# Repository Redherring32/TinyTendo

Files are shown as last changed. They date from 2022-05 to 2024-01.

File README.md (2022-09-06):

# Tiny 'Tendo
An open-source Gameboy sized handheld NES using real hardware

## DISCLAIMER:

TinyTendo is a complex project that has taken a ton of effort, and despite now being open source should still be considered somewhat experimental, should you find anything that isn't quite right, please file an issue.

Additionally, TinyTendo requires physically cutting and grinding ORIGINAL NES chips down smaller, this is a difficult, tedious, and risky process. 

You could KILL the chips if this is not done correctly, do this at your own risk, I am not responsible for damage to any hardware resulting from attempting to build this project.

## Repository Structure:

* Hardware: Contains all files relating to the hardware design for the various PCBs used for this project

* Software: Contains the software required for the brightness mod PCB

* 3D-CAD: Contains design files for the housing design

The files required to order PCBs can be found under releases.

TinyTendo Internals
	
This project is a derivitive of OpenTendo, and OpenTendo-Toploader, and is licensed accordingly. Please read the LICENSE in the repository for more info.

Since this project is open-source you may do as you like with it, whether that is to make TinyTendo for personal use, sell PCBs or assembled handhelds, or to use the provided info for further custom PCB work/designs.

*Note:* 
REAL NES chips from a real NES are required, clone chips cannot be used without some redesign of the motherboard, as they cannot be trimmed down as small.
A version of the PCB that supports them would be relatively easy to make, but I myself have no interest in doing so. (PRs to add a "clone" branch are welcome!)

And finally, I am NOT an EE, if you are at all disgusted by any aspect of the PCB designs, I am sorry. (PRs for this are also welcome :P)

## TO-DO:

* Write chip trimming guide to go over workflow and best practices

* Update readme image to reflect current hardware revision

* Figure out what I am forgetting to add to TO-DO

## License:

Licensed under
the TAPR Open Hardware License (www.tapr.org/OHL)

©Redherring32 2019-2022

All hardware contained within this repository was designed by me except the Brightness mod PCB.
The brightness mod PCB was designed by YveltalGriffin, and has been licensed under TAPR OHL with permission from the author.
The brightness PCB was designed using Eagle, all other hardware was designed using KiCAD.
The Brightness software was written by YveltalGriffin, and has been licensed under MIT with permission from the author, see LICENSE in software folder for details.
## Credits

In no particular order:

*FenrisWolfRetro* -Creating the wiring diagram in the Hardware folder.

*YveltalGriffin* -Designed the brightness mod PCB, and wrote the code for it, and was just a tremendous help.

*DiscoStarslayer* -Helping to inspire me to trim the chipset, without his joking suggestion to dremel the package and solder to the leads, I would not have started researching chip trimming.

*lidnariq* -Helping me diagnose my idiotic design blunders, might not have had the motivation to keep going on the project without their help.

*BucketMouse* -Designing cartridge PCBs for TinyTendo, and help with diagnosis work.

*MuraMasa* -Help with diagnosis work, sharing KiCAD footprints for early protos cause I kept messing mine up. :)

And to all of the awesome people in NESDev, you guys rock.

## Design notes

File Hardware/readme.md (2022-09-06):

Wiring Diagram made by FenrisWolfRetro

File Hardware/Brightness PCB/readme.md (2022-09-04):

Brightness PCB

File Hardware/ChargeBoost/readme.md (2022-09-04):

ChargeBoost

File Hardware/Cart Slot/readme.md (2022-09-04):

Cart Slot

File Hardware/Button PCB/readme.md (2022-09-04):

Button PCB

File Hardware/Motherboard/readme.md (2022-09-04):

PCB Photo

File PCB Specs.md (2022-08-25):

##PCB SPECS:

##Motherboard:
*4-Layers
*1.6mm thickness
*HASL finish

##ChargeBoost:
*2-Layers
*1.6mm thickness
*HASL finish

##AudioAmp
*2-Layers
*1.6mm thickness
*ENiG finish

##Button PCB:
*2-Layers
*1.6mm thickness
*ENiG finish

##Composite Amp:
*2-layers 
*0.6mm thickness
*HASL finish

##Brightness PCB:
*2-Layers
*1.6mm thickness
*HASL finish

##Cart SLot:
*2-Layers
*1.6mm thickness
*HASL finish

##Cart-Test:
*2-Layers
*1.6mm thickness
*ENiG finish

##TNY-NES-Adapter:
*2-Layers 
*1.2mm thickness
*ENiG finish

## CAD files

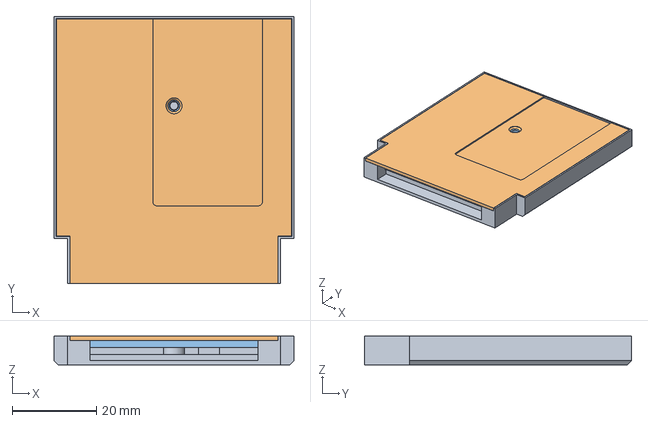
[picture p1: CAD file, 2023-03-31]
3D-CAD/TinyTendo Cartridge-Shell.step
57.0 x 63.5 x 6.80 mm

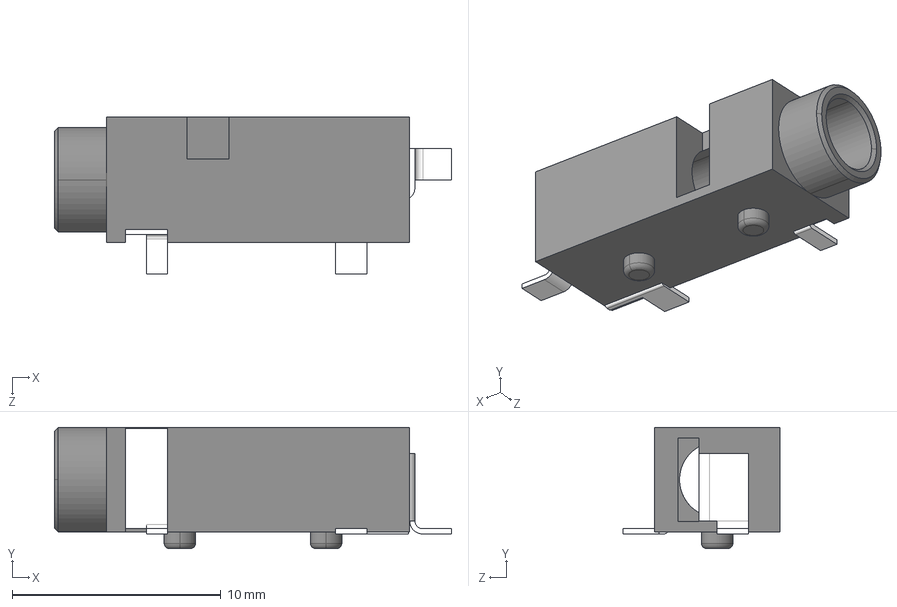
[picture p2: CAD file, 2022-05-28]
Hardware/Audio Amp/CUI_DEVICES_MJ-3523-SMT-TR.step
19.0 x 5.80 x 7.50 mm

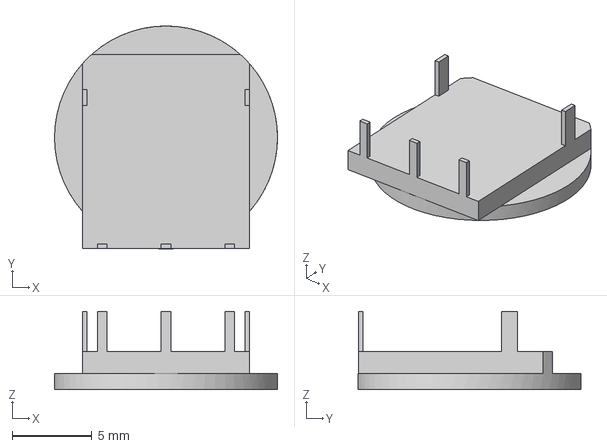
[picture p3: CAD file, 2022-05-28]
Hardware/Composite amp/Thumbwheel Pot v1.step
14.0 x 14.0 x 4.90 mm

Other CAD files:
3D-CAD/TinyTendo Cartridge-Shell.f3d

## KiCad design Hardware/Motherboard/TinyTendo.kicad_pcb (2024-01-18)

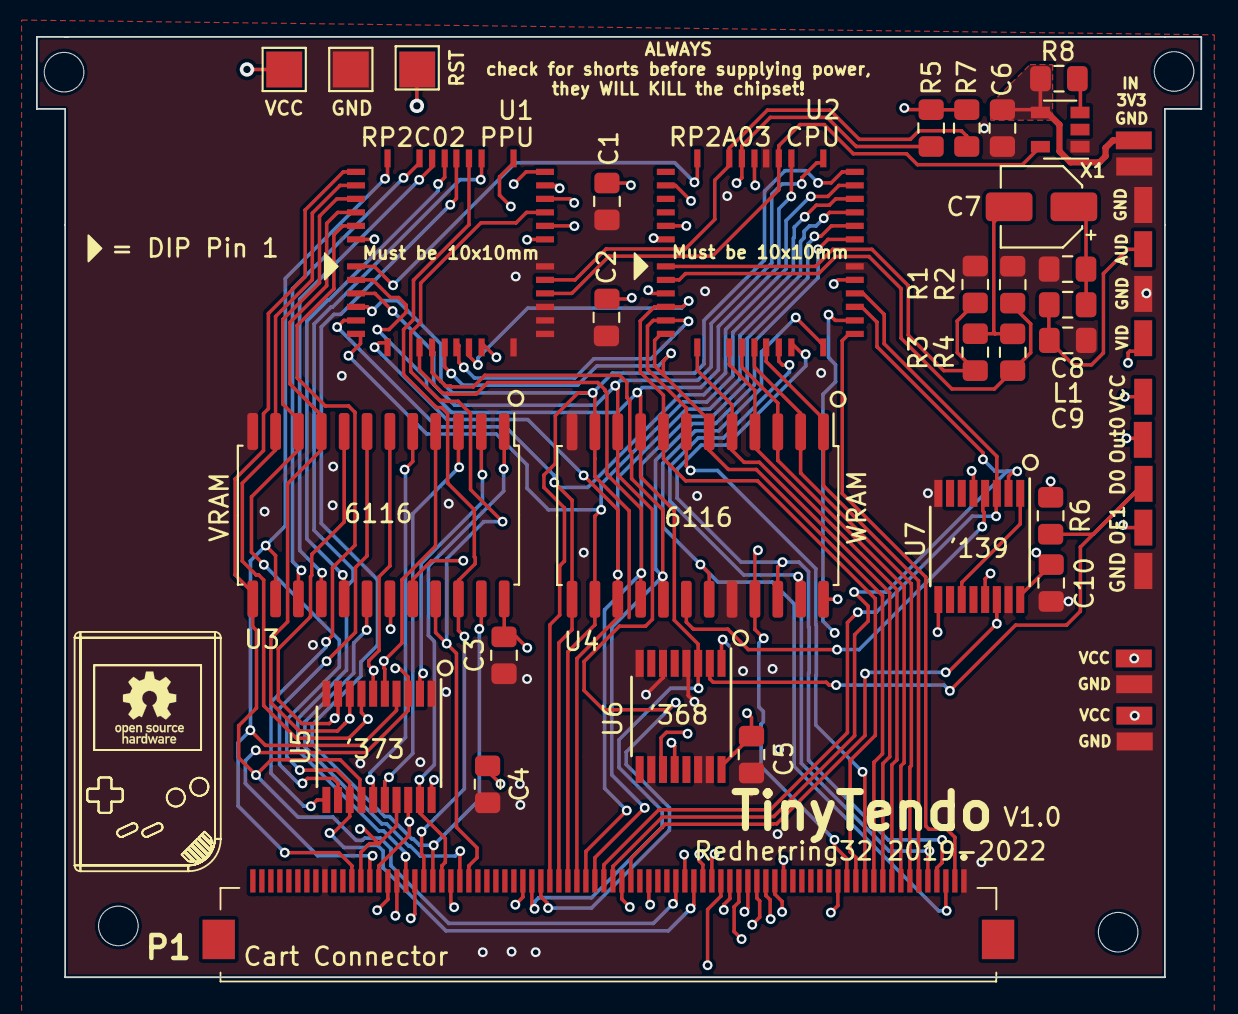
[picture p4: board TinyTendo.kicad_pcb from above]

Board: 4 copper layers, 64.7 x 52.2 mm, 50 parts (0 on the bottom side), 75 nets.

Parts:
C1, C2, C4, C5, C10: 10nF; C_0805_2012Metric_Pad1.15x1.40mm_HandSolder
C3, C6, C9: 0.1uF; C_0805_2012Metric_Pad1.15x1.40mm_HandSolder
C7: 1uF; CP_Elec_4x5.3
C8: 220pF; C_0805_2012Metric_Pad1.15x1.40mm_HandSolder
H1, H2, H3, H4: MountingHole_2.2mm_M2
J1, J2, J2#2, J2#3, J4#2, J5#2, J6, J6#2, J6#3, J6#4, J6#5, J7, J7#2, J8, J9: Conn_01x01_Male; SolderPad
J3, J4, J5: Conn_01x01_Male; TestPoint_Pad_2.0x2.0mm
L1: 39uH; L_0805_2012Metric_Pad1.15x1.40mm_HandSolder
P1: 72-Pin Connector; XF3M80151BE
R1, R2: 160; R_0805_2012Metric_Pad1.15x1.40mm_HandSolder
R3: 200; R_0805_2012Metric_Pad1.15x1.40mm_HandSolder
R4: 100; R_0805_2012Metric_Pad1.15x1.40mm_HandSolder
R5, R6, R7: 10K; R_0805_2012Metric_Pad1.15x1.40mm_HandSolder
R8: 1K; R_0805_2012Metric_Pad1.15x1.40mm_HandSolder
U1: RP2C02 PPU; Cut chip
U2: RP2A03 CPU; Cut chip
U3: 6116 (VRAM); SOIC-24W_7.5x15.4mm_P1.27mm
U4: 6116 (WRAM); SOIC-24W_7.5x15.4mm_P1.27mm
U5: 74HC373; TSSOP-20_4.4x6.5mm_P0.65mm
U6: 40H368 (CI); TSSOP-16_4.4x5mm_P0.65mm
U7: 74HC139; TSSOP-16_4.4x5mm_P0.65mm
X1: SiT2001B; SOT-23-5

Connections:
/3V3: C6.2, J1.1, R8.2, X1.4
/4016-D0: J4#2.1, R6.2, U6.2
/ALE: U1.39, U5.11
/AUDIO: C9.1, J8.1, L1.2
/CPU-A0: P1.13, U1.12, U2.4, U4.8
/CPU-A1: P1.12, U1.11, U2.5, U4.7
/CPU-A2: P1.11, U1.10, U2.6, U4.6
/CPU-A3: P1.10, U2.7, U4.5
/CPU-A4: P1.9, U2.8, U4.4
/CPU-A5: P1.8, U2.9, U4.3
/CPU-A6: P1.7, U2.10, U4.2
/CPU-A7: P1.6, U2.11, U4.1
/CPU-A8: P1.5, U2.12, U4.23
/CPU-A9: P1.4, U2.13, U4.22
/CPU-A10: P1.3, U2.14, U4.19
/CPU-A11: P1.2, U2.15
/CPU-A12: P1.39, U2.16
/CPU-A13: P1.40, U2.17, U7.2
/CPU-A14: P1.41, U2.18, U7.3
/CPU-A15: U2.19, U7.13
/CPU-D0: P1.49, U1.2, U2.28, U4.9, U6.3
/CPU-D1: P1.48, U1.3, U2.27, U4.10
/CPU-D2: P1.47, U1.4, U2.26, U4.11
/CPU-D3: P1.46, U1.5, U2.25, U4.13
/CPU-D4: P1.45, U1.6, U2.24, U4.14
/CPU-D5: P1.44, U1.7, U2.23, U4.15
/CPU-D6: P1.43, U1.8, U2.22, U4.16
/CPU-D7: P1.42, U1.9, U2.21, U4.17
/CPU-R~W: P1.14, U1.1, U2.34, U4.21
/GND: C1.1, C2.1, C3.1, C4.1, C5.1, C6.1, C8.1, C9.2, C10.1, J2.1, J2#2.1, J2#3.1, J3.1, J6#4.1, J7.1, J7#2.1, P1.1, P1.72, R1.1, R2.1, U1.14, U1.15, U1.16, U1.17, U1.20, U2.20, U2.30, U3.12, U4.12, U4.20, U5.1, U5.10, U6.4, U6.6, U6.8, U6.10, U6.14, U6.15, U7.8, U7.15, X1.1
/M2: P1.38, U2.31, U7.14
/OUT-0: J5#2.1, U2.39
/PPU-A0: P1.29, U3.8, U5.9
/PPU-A1: P1.28, U3.7, U5.12
/PPU-A2: P1.27, U3.6, U5.6
/PPU-A3: P1.26, U3.5, U5.15
/PPU-A4: P1.25, U3.4, U5.5
/PPU-A5: P1.24, U3.3, U5.16
/PPU-A6: P1.23, U3.2, U5.2
/PPU-A7: P1.59, U3.1, U5.19
/PPU-A8: P1.60, U1.30, U3.23
/PPU-A9: P1.61, U1.29, U3.22
/PPU-A10: P1.63, U1.28
/PPU-A11: P1.62, U1.27
/PPU-A12: P1.64, U1.26
/PPU-A13: P1.65, U1.25, U6.12
/PPU-D0: P1.30, U1.38, U3.9, U5.8
/PPU-D1: P1.31, U1.37, U3.10, U5.13
/PPU-D2: P1.32, U1.36, U3.11, U5.7
/PPU-D3: P1.33, U1.35, U3.13, U5.14
/PPU-D4: P1.69, U1.34, U3.14, U5.4
/PPU-D5: P1.68, U1.33, U3.15, U5.17
/PPU-D6: P1.67, U1.32, U3.16, U5.3
/PPU-D7: P1.66, U1.31, U3.17, U5.18
/PPU-~A13: P1.58, U6.11
/PPU-~CE: U1.13, U7.5
/PPU-~RD: P1.21, U1.24, U3.20
/PPU-~WE: P1.56, U1.23, U3.21
/SOUND-1: R1.2, R3.2, U2.1
/SOUND-2: R2.2, R4.2, U2.2
/SYS-CLK: U1.18, U2.29, X1.5
/VCC: C1.2, C2.2, C3.2, C4.2, C5.2, C10.2, J4.1, J6.1, J6#2.1, J6#3.1, P1.36, R5.1, R6.1, R7.1, U1.22, U1.40, U2.40, U3.24, U4.24, U5.20, U6.16, U7.16
/VIDEO: J9.1, U1.21
/VRAM-A10: P1.22, U3.19
/VRAM-~CE: P1.57, U3.18
/WRAM-~CE: U4.18, U7.4
/~IRQ: P1.15, R5.2, U2.32
/~NMI: R7.2, U1.19, U2.33
/~OE1: J6#5.1, U2.36, U6.1
/~ROMSEL: P1.50, U7.9
/~RST: J5.1, U2.3
unnamed: C7.1, C8.2, L1.1
unnamed: C7.2, R3.1, R4.1
unnamed: R8.1, X1.3
unnamed: U7.1, U7.11

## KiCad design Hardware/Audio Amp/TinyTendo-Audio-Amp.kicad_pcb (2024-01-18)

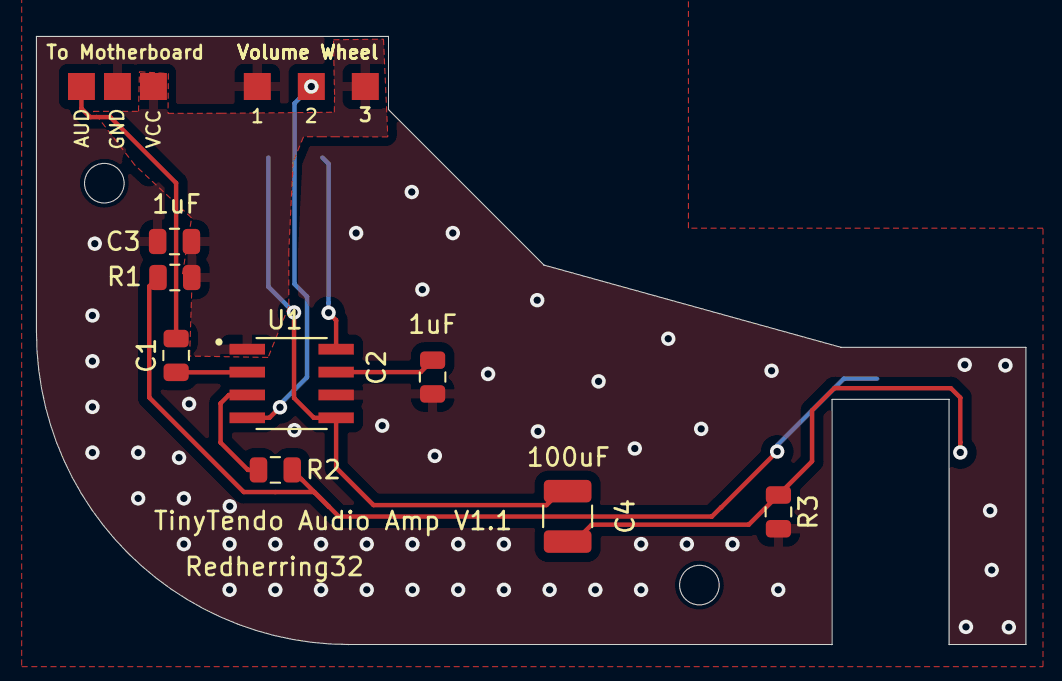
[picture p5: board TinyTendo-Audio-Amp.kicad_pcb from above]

Board: 2 copper layers, 55.0 x 33.8 mm, 14 parts (0 on the bottom side), 11 nets.

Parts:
 : MountingHole_2.2mm_M2
 #2: MountingHole_2.2mm_M2
C1: 0.22uF; C_0805_2012Metric
C2, C3: 1uF; C_0805_2012Metric
C4: 100uF; C_1210_3225Metric
J1: Conn_Coaxial; AUD-IN
J2: MJ-3523-SMT; CUI_MJ-3523-SMT-Inline
LS1: Speaker
R1, R2: 100K; R_0805_2012Metric
R3: 150R; R_0805_2012Metric
U1: LM4865M; SOIC127P599X175-8N
Volume Wheel: 10K; VolPot

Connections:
/GND: C2.2, C3.2, J1.2, J2.1, R3.2, U1.6, Volume Wheel.3
/VDD: C3.1, J1.3, R1.1, U1.1, Volume Wheel.1
unnamed: C1.1, U1.2
unnamed: C1.2, J1.1
unnamed: C2.1, U1.7
unnamed: C4.1, LS1.1, U1.5
unnamed: C4.2, J2.2, R3.1
unnamed: J2.10, R1.2, R2.1
unnamed: LS1.2, U1.8
unnamed: R2.2, U1.3
unnamed: U1.4, Volume Wheel.2

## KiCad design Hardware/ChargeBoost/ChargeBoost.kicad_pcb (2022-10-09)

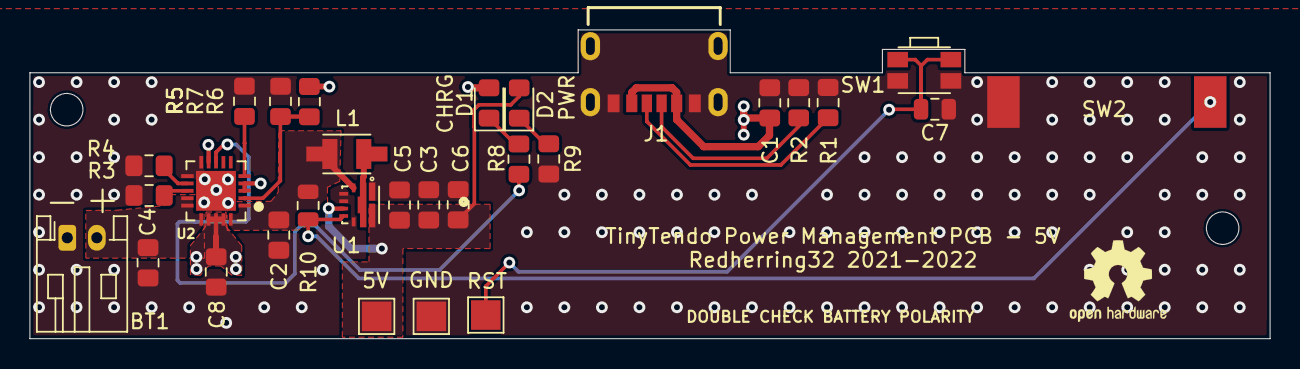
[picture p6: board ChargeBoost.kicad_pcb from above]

Board: 2 copper layers, 84.0 x 20.9 mm, 32 parts (0 on the bottom side), 17 nets.

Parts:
 : MountingHole_2.2mm_M2
 #2: MountingHole_2.2mm_M2
BT1: 2800mAh; JST_PH_S2B-PH-K_1x02_P2.00mm_Horizontal-Mirrored
C1, C2, C4, C8: 10uF; C_0805_2012Metric_Pad1.15x1.40mm_HandSolder
C3, C5, C6: 22uF; C_0805_2012Metric_Pad1.15x1.40mm_HandSolder
C7: 1uF; C_0805_2012Metric
D1: Red; LED_0805_2012Metric_Pad1.15x1.40mm_HandSolder
D2: BLUE; LED_0805_2012Metric_Pad1.15x1.40mm_HandSolder
J1: USB4125-GF-A_REVA2; GCT_USB4125-GF-A_REVA2
J3, J4, J5: Conn_01x01_Male; TestPoint_Pad_2.0x2.0mm
L1: 1uH; IND_LQH32CN1R0M23L
R1, R2: 5K1; R_0805_2012Metric_Pad1.15x1.40mm_HandSolder
R3, R8: 1K; R_0805_2012Metric_Pad1.15x1.40mm_HandSolder
R4, R7: 100K; R_0805_2012Metric_Pad1.15x1.40mm_HandSolder
R5: 15K; R_0805_2012Metric_Pad1.15x1.40mm_HandSolder
R6: 270K; R_0805_2012Metric_Pad1.15x1.40mm_HandSolder
R9: 91R; R_0805_2012Metric_Pad1.15x1.40mm_HandSolder
R10: 200R; R_0805_2012Metric
SW1: SW_Push; SW_SPST_EVQP7A
SW2: PWR
U1: TPS61235PRWLT; CONV_TPS61235PRWLT
U2: MCP73871-2AAI_ML; QFN50P400X400X100-21N

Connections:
/GND: BT1.2, C1.2, C2.2, C3.2, C4.2, C5.2, C6.2, C7.2, C8.2, J1.A12, J1.B12, J1.S1, J3.1, R1.2, R2.2, R3.2, R4.2, R5.2, R7.2, R9.2, SW1.1, SW2.1, U1.1, U1.4, U1.5, U1.8, U2.10, U2.11, U2.21
/RST: C7.1, J5.1, SW1.2
/VBAT: C2.1, L1.1, R10.1, U1.3, U2.1, U2.20
/VBUS: C1.1, C8.1, D1.2, J1.A9, J1.B9, R6.1, U2.3, U2.4, U2.9, U2.17, U2.18, U2.19
/VOUT: C3.1, C5.1, C6.1, D2.2, J4.1, U1.6, U1.9
unnamed: BT1.1, C4.1, U2.14, U2.15, U2.16
unnamed: D1.1, R8.1
unnamed: D2.1, R9.1
unnamed: J1.A5, R2.1
unnamed: J1.B5, R1.1
unnamed: L1.2, U1.2
unnamed: R3.1, U2.13
unnamed: R4.1, U2.12
unnamed: R5.1, U2.5
unnamed: R6.2, R7.1, U2.2
unnamed: R8.2, U2.8
unnamed: R10.2, SW2.2, U1.7

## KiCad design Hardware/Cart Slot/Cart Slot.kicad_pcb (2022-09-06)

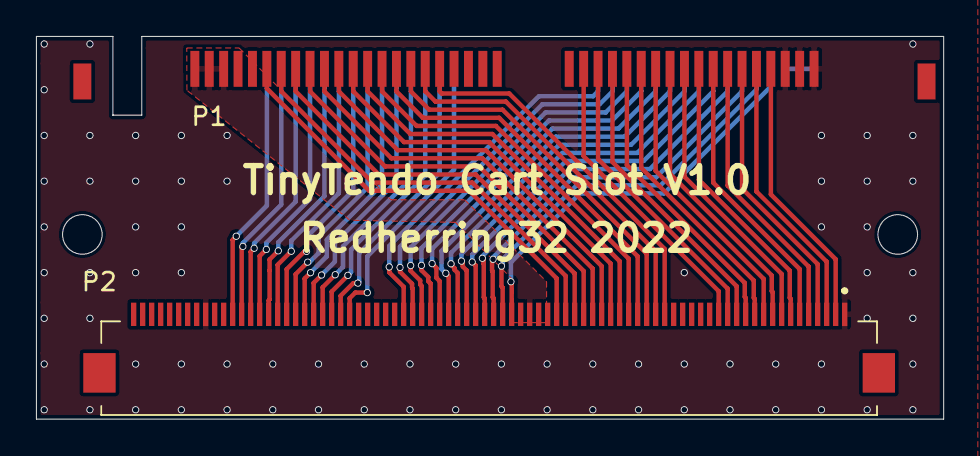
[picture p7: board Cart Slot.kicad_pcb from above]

Board: 2 copper layers, 50.4 x 21.3 mm, 4 parts (0 on the bottom side), 56 nets.

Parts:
 : MountingHole_2.2mm_M2
 #2: MountingHole_2.2mm_M2
P1: 72-Pin Connector; Cart Slot
P2: 72-Pin Connector; XF3M80151BE

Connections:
/CPU-A0: P1.13, P2.13
/CPU-A1: P1.12, P2.12
/CPU-A2: P1.11, P2.11
/CPU-A3: P1.10, P2.10
/CPU-A4: P1.9, P2.9
/CPU-A5: P1.8, P2.8
/CPU-A6: P1.7, P2.7
/CPU-A7: P1.6, P2.6
/CPU-A8: P1.5, P2.5
/CPU-A9: P1.4, P2.4
/CPU-A10: P1.3, P2.3
/CPU-A11: P1.2, P2.2
/CPU-A12: P1.39, P2.39
/CPU-A13: P1.40, P2.40
/CPU-A14: P1.41, P2.41
/CPU-D0: P1.49, P2.49
/CPU-D1: P1.48, P2.48
/CPU-D2: P1.47, P2.47
/CPU-D3: P1.46, P2.46
/CPU-D4: P1.45, P2.45
/CPU-D5: P1.44, P2.44
/CPU-D6: P1.43, P2.43
/CPU-D7: P1.42, P2.42
/CPU-R~W: P1.14, P2.14
/GND: P1.1, P1.72, P2.1, P2.72
/M2: P1.38, P2.38
/PPU-A0: P1.29, P2.29
/PPU-A1: P1.28, P2.28
/PPU-A2: P1.27, P2.27
/PPU-A3: P1.26, P2.26
/PPU-A4: P1.25, P2.25
/PPU-A5: P1.24, P2.24
/PPU-A6: P1.23, P2.23
/PPU-A7: P1.59, P2.59
/PPU-A8: P1.60, P2.60
/PPU-A9: P1.61, P2.61
/PPU-A10: P1.63, P2.63
/PPU-A11: P1.62, P2.62
/PPU-A12: P1.64, P2.64
/PPU-A13: P1.65, P2.65
/PPU-D0: P1.30, P2.30
/PPU-D1: P1.31, P2.31
/PPU-D2: P1.32, P2.32
/PPU-D3: P1.33, P2.33
/PPU-D4: P1.69, P2.69
/PPU-D5: P1.68, P2.68
/PPU-D6: P1.67, P2.67
/PPU-D7: P1.66, P2.66
/PPU-~A13: P1.58, P2.58
/PPU-~RD: P1.21, P2.21
/PPU-~WE: P1.56, P2.56
/VCC: P1.36, P2.36
/VRAM-A10: P1.22, P2.22
/VRAM-~CE: P1.57, P2.57
/~IRQ: P1.15, P2.15
/~ROMSEL: P1.50, P2.50

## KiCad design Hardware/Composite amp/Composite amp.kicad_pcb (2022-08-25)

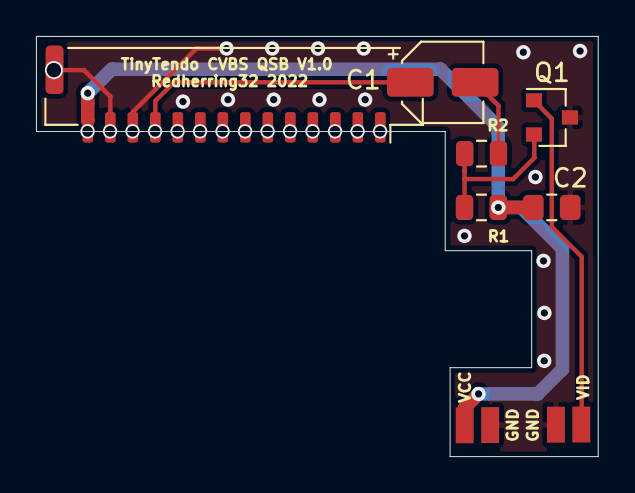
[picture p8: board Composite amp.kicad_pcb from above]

Board: 2 copper layers, 31.2 x 23.3 mm, 10 parts (0 on the bottom side), 6 nets.

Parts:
C1: 100uF; CP_Elec_4x4.5
C2: 22uF; C_0805_2012Metric_Pad1.15x1.40mm_HandSolder
GND1, GND2: TestPoint; SolderPad
J1: Conn_01x14_Female; JST_GH_SM14B-GHS-TB_1x14-1MP_P1.25mm_Horizontal
Q1: MMBT3906; SOT-23
R1: 300R; R_0805_2012Metric
R2: 110R; R_0805_2012Metric
VCC1: TestPoint; SolderPad
VID1: TestPoint; SolderPad

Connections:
/5V: C2.1, J1.14, R1.1, VCC1.1
/GND: C2.2, GND1.1, GND2.1, J1.12, J1.13, Q1.3
/VIDEO-IN: Q1.1, VID1.1
/VIDEO-OUT: C1.1, J1.11
unnamed: C1.2, R2.1
unnamed: Q1.2, R1.2, R2.2

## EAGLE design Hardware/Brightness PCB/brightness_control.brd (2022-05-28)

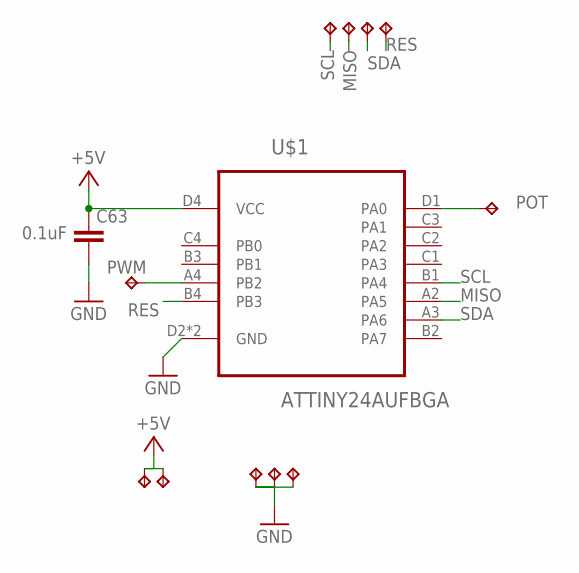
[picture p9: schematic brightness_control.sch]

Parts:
C63: 0.1uF; C0402
TP1, TP3, TP4, TP5, TP6, TP7, TP8, TP10, TP11, TP12, TP13: TPTP12R; TP12R
U$1: ATTINY24AUFBGA; UFBGA-15

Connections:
+5V: C63.1, TP3.TP, TP4.TP, U$1.D4 (VCC)
GND: C63.2, TP1.TP, TP5.TP, TP6.TP, U$1.D2 (GND), U$1.D3 (GND)
MISO: TP11.TP, U$1.A2 (PA5)
POT: TP7.TP, U$1.D1 (PA0)
PWM: TP8.TP, U$1.A4 (PB2)
RES: TP13.TP, U$1.B4 (PB3)
SCL: TP10.TP, U$1.B1 (PA4)
SDA: TP12.TP, U$1.A3 (PA6)

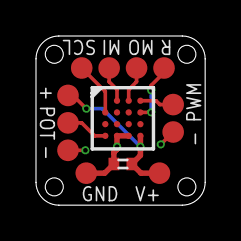
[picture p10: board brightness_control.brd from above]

Board: 2 copper layers, 9.4 x 9.4 mm, 13 parts (0 on the bottom side), 8 nets.

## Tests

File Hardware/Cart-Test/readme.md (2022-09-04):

Cart Test

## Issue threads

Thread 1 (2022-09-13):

EN pull-up resistor missing on ChargeBoost

Redherring32, 2022-09-13:
The pull up resistor for the buck boost enable line is missing on the ChargeBoost PCB (Really not sure what happened), working on a fix currently.

Redherring32, 2022-10-09:
Fixed by Pull Request #2

Closed 2022-10-09.

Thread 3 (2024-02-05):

White screen

GenuineHili, 2024-02-05:
So I assembled the motherboard, charge boost pcb and cart slot pcb and gave it a try but I always get a white screen when I turn it on.
I tested the cartridge with the cart test, so I know the cartridge is working. Is the audio pcb and button pcb mandatory for the NES to boot?

Pearus, 2024-02-05:
> So I assembled the motherboard, charge boost pcb and cart slot pcb and gave it a try but I always get a white screen when I turn it on. I tested the cartridge with the cart test, so I know the cartridge is working. Is the audio pcb and button pcb mandatory for the NES to boot?

Audio and button PCBs are not required for booting. If you're getting a white screen, double check the connections on the CPU. If you have the board to test full sized games, that's another good thing to try to confirm if it's something with the connection to the TinyTendo cartridge slot.

GenuineHili, 2024-03-11:
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
It's working now. I resoldered the 80-pin connector on the cart slot PCB and now it's working. Thank you for your advice.

Pearus, 2024-03-11:
> ![IMG_20240311_132507285](https://private-user-images.githubusercontent.com/147345143/311771046-8b41c50a-c64d-402c-a06b-0a79d4b32b41.jpg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) It's working now. I resoldered the 80-pin connector on the cart slot PCB and now it's working. Thank you for your advice.

Awesome, glad you got it running!

Closed 2024-03-11.

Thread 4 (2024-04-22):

Brightness Mod

GenuineHili, 2024-04-22:
Is it normal that the screen is rather dark compared to when it's not installed, even when the brightness wheel is all the way up?

Pearus, 2024-04-23:
I experienced the same, the brightness was significantly lower.

You can play around with max brightness by adjusting "15" in the Arduino sketch to values between 0 and 255:
`analogWrite(8, map(pot, 0, 1023, 0, 15));`

I would be careful and start with small increments.

GenuineHili, 2024-04-24:
Ok I set the value to 100 and now it's nice and bright. Thank you for your help.

Closed 2024-04-24.

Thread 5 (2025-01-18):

Parasitic Drain with ChargeBoost PCB

Pearus, 2025-01-18:
There's a known issue with the ChargeBoost PCB which causes parasitic drain. Resistor R10 on the EN pin of the TPS61235PRWLT is configured as a pull-up resistor instead of a pull-down resistor.

The workaround to resolve the parasitic drain is to do the following:

1.  Move resistor R10 so that the bottom is aligned with the ground side of capacitor C2 and the top is soldered to the pad connected to the EN pin of the TPS61235PRWLT.
2. Connect the ground side of capacitor C2 to the bottom of resistor R10 using a wire, lead, or solder blob.

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

3. Connect a wire to the original pad the top of resistor R10 was connected to, long enough to reach the left lead of the power switch.

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

4.  De-solder the left leg of the power switch from the ground pad and cover the pad with Kapton tape or another non-conductive material.
5. Connect the soldered wire to the left leg of the power switch.

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

GenuineHili, 2025-01-20:
Yo, thanks for that workaround. I always thought that my battery cells are the problem.
The only downside to this is that the power switch is inverted, which isn't a big deal.

GenuineHili, 2025-01-20:
Ok I will try it with a 10k resistor and measure the voltage over some days.

GenuineHili, 2025-01-30:
Ok so with a 10k resistor the voltage drops about 0,007V per day. I then tried the same with a 200k resistor where the voltage drops about 0,002V per day. So that's basically nothing.

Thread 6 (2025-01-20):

Undersized Capacitor C2 on ChargeBoost PCB

Pearus, 2025-01-20:
Capacitor C2 on the ChargeBoost may be undersized, resulting in voltage drops which prevent the TPS61235PRWLT from boosting to 5V. This is more noticeable when the batteries are not fully charged.

To fix this a second capacitor can be stacked on top of C2, this can be of the same value or higher.

GenuineHili, 2025-01-21:
Does that mean that the recommend value for C2 is around 22µF?

Pearus, 2025-01-21:
> Does that mean that the recommend value for C2 is around 22µF?

Yup, that should work, I just stacked a second 10µF on top because that's what I had.

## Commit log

2022-05-28 + Add Working Files + Initial Readme Draft
    [Button PCB.kicad_pcb, Button PCB.sch, Button PCB.step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]
2022-05-29 + Updated README.md + Fixed schematic/pinout error with Q1, and added decoupling capacitor to Composite Amp
    [Composite amp.kicad_pcb, Composite amp.sch]
2022-06-15 + Motherboard is now V1.0 + Redesigned ScreenReg for improved reliability + Added both versions of ChargeBoost + Remove now redundant files/directories
    [Button PCB.kicad_pcb, Cart Slot.kicad_pcb, Cart-Test.kicad_pcb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]
2022-08-25 +Remove redundant files
    [Button PCB.kicad_pcb, Button PCB.sch, Button PCB.step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]
2022-09-04 + Added TinyTendo Cart Shell CAD files
    [TinyTendo Cartridge-Shell.f3z, TinyTendo Cartridge-Shell.step]
2022-09-06 + Updated FFC footprint on Cart Slot and Cart-Test
    [Cart Slot.kicad_pcb, Cart-Test.kicad_pcb]
2022-09-14 Redid ChargeBoost layout, and added EN pull up, and RST capacitor
    [ChargeBoost.kicad_pcb, ChargeBoost.sch]
2022-10-01 + Fixed error on InCU1 layer + Added missing pads for audio amp power + Removed redundant autosave files
    [TinyTendo.kicad_pcb]
2022-11-20 +Update Motherboard to use more available SiT2001B oscillator.
    [TinyTendo.kicad_pcb, TinyTendo.sch]
2023-03-31 + Fixed isue where Cart slot would strain screwposts overtime + Updated Cartridge shell design to make printing easier, and make room for TNY-TKROM boards
    [TinyTendo Cartridge-Shell.f3d, TinyTendo Cartridge-Shell.f3z, TinyTendo Cartridge-Shell.step]
2024-01-18 + Corrected duplicate reference error in Chargeboost.sch
    + Made changes to Audio Amp PCB to improve screwpost locations
    + Made changes to Button PCB to improve screwpost locations
    + Moved screen up 6mm to even out bezels on shell
    + Altered shell to improve screwpost placement, and add optional suppport for threaded inserts
    + Added 2 new shell variants, 1 with a logo via multicolor printing and threaded inserts, 1 with just threaded inserts
    [Button PCB.kicad_pcb, ChargeBoost.sch, TinyTendo-Audio-Amp.kicad_pcb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]
